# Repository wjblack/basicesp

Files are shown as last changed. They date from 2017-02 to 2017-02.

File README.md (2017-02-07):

BasicESP Hardware
=================

Introduction
------------

This repository houses the PCB design for the BasicESP project.  The
[ESP8266](https://en.wikipedia.org/wiki/ESP8266) is a super-cheap chip that
has:

   * 802.11n WiFi
   * An 80 MHz Tensilica Xtensa microcontroller
   * 64+96k of I+D RAM
   * An SDIO interface
   * And a bunch of GPIO, PWM, and other SoCish goodness

It can be used either as a SDIO-attached device or as a standalone
microcontroller and is available for about $2 via
[AliExpress](http://aliexpress.com) on a module such as the
[ESP-12F](http://www.esp8266.com/viewtopic.php?f=5&t=5520), which is what this
PCB design assumes.  Assuming an ESP-12, this board adds:

   * 2mm pads for the ESP wifi module (the board has overhang/clearance space
     for the module so that the antenna gets no interference from the board).
     This makes it very easy to mount the ESP to the board via 2mm header pins.
   * Built-in 5V->3.3V regulator.
   * A programming switch (to easily put the ESP into programming mode on boot).
   * A serial header (to easily attach an
     [FTDI cable](https://www.sparkfun.com/products/9718)).
   * All the various resistors needed for mode setting and whatnot.

Revisions
---------

[Revison 1](rev1/) was the first pass and was produced in a small batch at
[PCBWay](http://pcbway.com) in January 2017.  It lacked some filter capacitors
that caused issues with some sensors and had various other shortcomings (see
the docs inside for details).

[Revision 2](rev2/) is being produced now at PCBWay.  It includes filter caps
on the power regulator, mounting holes, a power cutoff jumper, and more pins
broken out.

Thanks
------

Many thanks to Niklas Wennerstrand for his excellent series of [intro videos
for kicad on Youtube](https://www.youtube.com/watch?v=uT1QnBSRLHs).  His notes
on producing the output for the manufacturer were particularly useful.

Copying
-------

(C) 2016-17 by [BJ Black](mailto:bj@wjblack.com)

This design is released under the [WTFPL](http://www.wtfpl.net/about/) license
and escapes unto an unsuspecting planet with NO WARRANTY WHATSOEVER, expressed
or implied.  Have fun, ya filthy animals ;-)

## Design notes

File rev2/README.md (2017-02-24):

BasicESP Hardware Revision 2.0
==============================

Introduction
------------

This PCB design is the second in the basicesp line.  The basicesp is designed
to use the ESP-12 module and has:

   * 2mm pads for the ESP wifi module (the board has overhang/clearance space
     for the module so that the antenna gets no interference from the board)
   * Built-in 5V->3.3V regulator
   * A programming switch
   * A serial header
   * All the various resistors needed for mode setting

A GPIO header on the left side has the following pinout (from the top):

   1. ADC
   2. GPIO5 (NodeMCU IO Index 1)
   3. GPIO4 (Index 2)
   4. GPIO16 (Index 0)
   5. GPIO14 (Index 5)
   6. GPIO12 (Index 6)
   7. GPIO13 (Index 7)
   8. +5V
   9. GND
   10. +3.3V

Notably an I2C display (like the Sainsmart LCD2004 controller) can be wired
straight to pins 3-6 without any gymnastics.  A typical PIR motion sensor
module can be wired to pins 4-6 with minimal gymnastics (swapping the OUT and
either VCC or GND connection to match ends).

Production and Files
--------------------

This board was sent to manufacture on 6 Feb 2017.

The design was done using kicad for both schematic, netlist, and PCB layout.
The kicad source files are all in [kicad/](kicad/).

When assembled, the board should look like this:

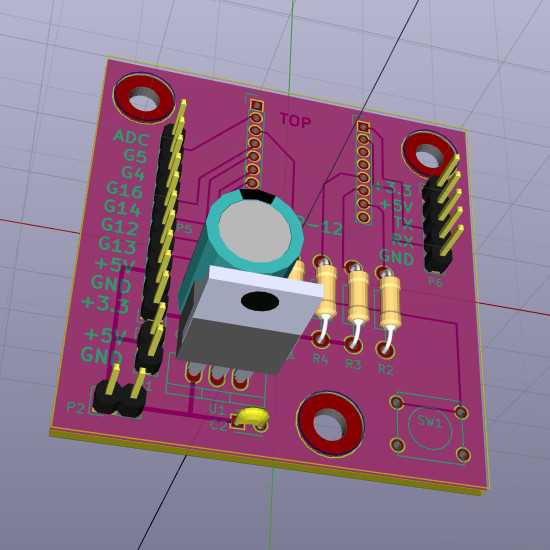
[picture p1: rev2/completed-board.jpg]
Completed board


And here is a [PDF of the schematic](schematic.pdf).

Shortcomings
------------

Revision A had two disconnected nodes (notably the +5V through the power header
and a filled region break for ground).  That's been fixed in rev 2.0b.

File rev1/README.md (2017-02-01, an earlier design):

BasicESP Hardware Revision 1.0
==============================

Introduction
------------

This PCB design was the first manufactured in the basicesp line.  The basicesp
is designed to use the ESP-12 module and has:

   * 2mm pads for the ESP wifi module (the board has overhang/clearance space
     for the module so that the antenna gets no interference from the board)
   * Built-in 5V->3.3V regulator
   * A programming switch
   * A serial header
   * All the various resistors needed for mode setting

A GPIO header on the left side has the following pinout (from the top):

   1. GPIO16 (NodeMCU IO Index 0)
   2. GPIO14 (Index 5)
   3. GPIO12 (Index 6)
   4. GPIO13 (Index 7)
   5. +5V
   6. GND
   7. +3.3V

Notably an I2C display (like the Sainsmart LCD2004 controller) can be wired
straight to pins 3-6 without any gymnastics.  A typical PIR motion sensor
module can be wired to pins 4-6 with minimal gymnastics (swapping the OUT and
either VCC or GND connection to match ends).

Production and Files
--------------------

This board was produced in a 10-unit proto batch at pcbway in Jan, 2017.  The
file bundle I sent to them is in basicesp.wjblack.com.rev.1.0b.zip.

The design was done using kicad for both schematic, netlist, and PCB layout.
The kicad source files are all in [kicad/](kicad/).

When assembled, the board looks like this:

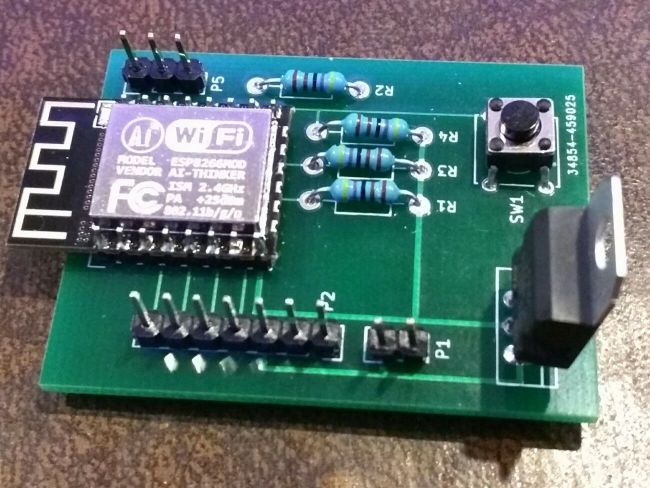
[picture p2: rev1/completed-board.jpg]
Completed board


And here is a [PDF of the schematic](schematic.pdf).

Ease of Use
-----------

Developing with this board isn't too bad (indeed, it's much easier to solder up than the 16 individual wires I had to wire for other projects involving the
PIA 2mm pitch).

The parts are surprisingly not too heat-sensitive--I was able to get away with
a fine tip soldering iron and light solder direct on all joints (there are a
lot of plain header connects, which are just straightforward through-hole
soldering).

Shortcomings
------------

The biggest problem with this design is that it does not include the
manufacturer-recommended capacitors for the 3.3V regulator.  The ESP module
doesn't seem to care too much, but variations in power wreak havoc with the PIR
module I tried (soldering the caps directly to the regulator pins afterward
worked well to mitigate those problems).  This will be fixed in Rev 2.

Mounting holes will be added in Rev 2.

It would have been nice to put a +5V rail by the serial so it could be powered
(albeit temporarily) by a FTDI cable all on one side (the evils of attempting
this are debatable--you can *kinda* get away with it if the ESP isn't drawing
too much current.  Real EEs' heads will be exploding right about now, though).
A power and/or reset switch would be a nice-to-have, as would breaking out the
two GPIO pins I left NC.

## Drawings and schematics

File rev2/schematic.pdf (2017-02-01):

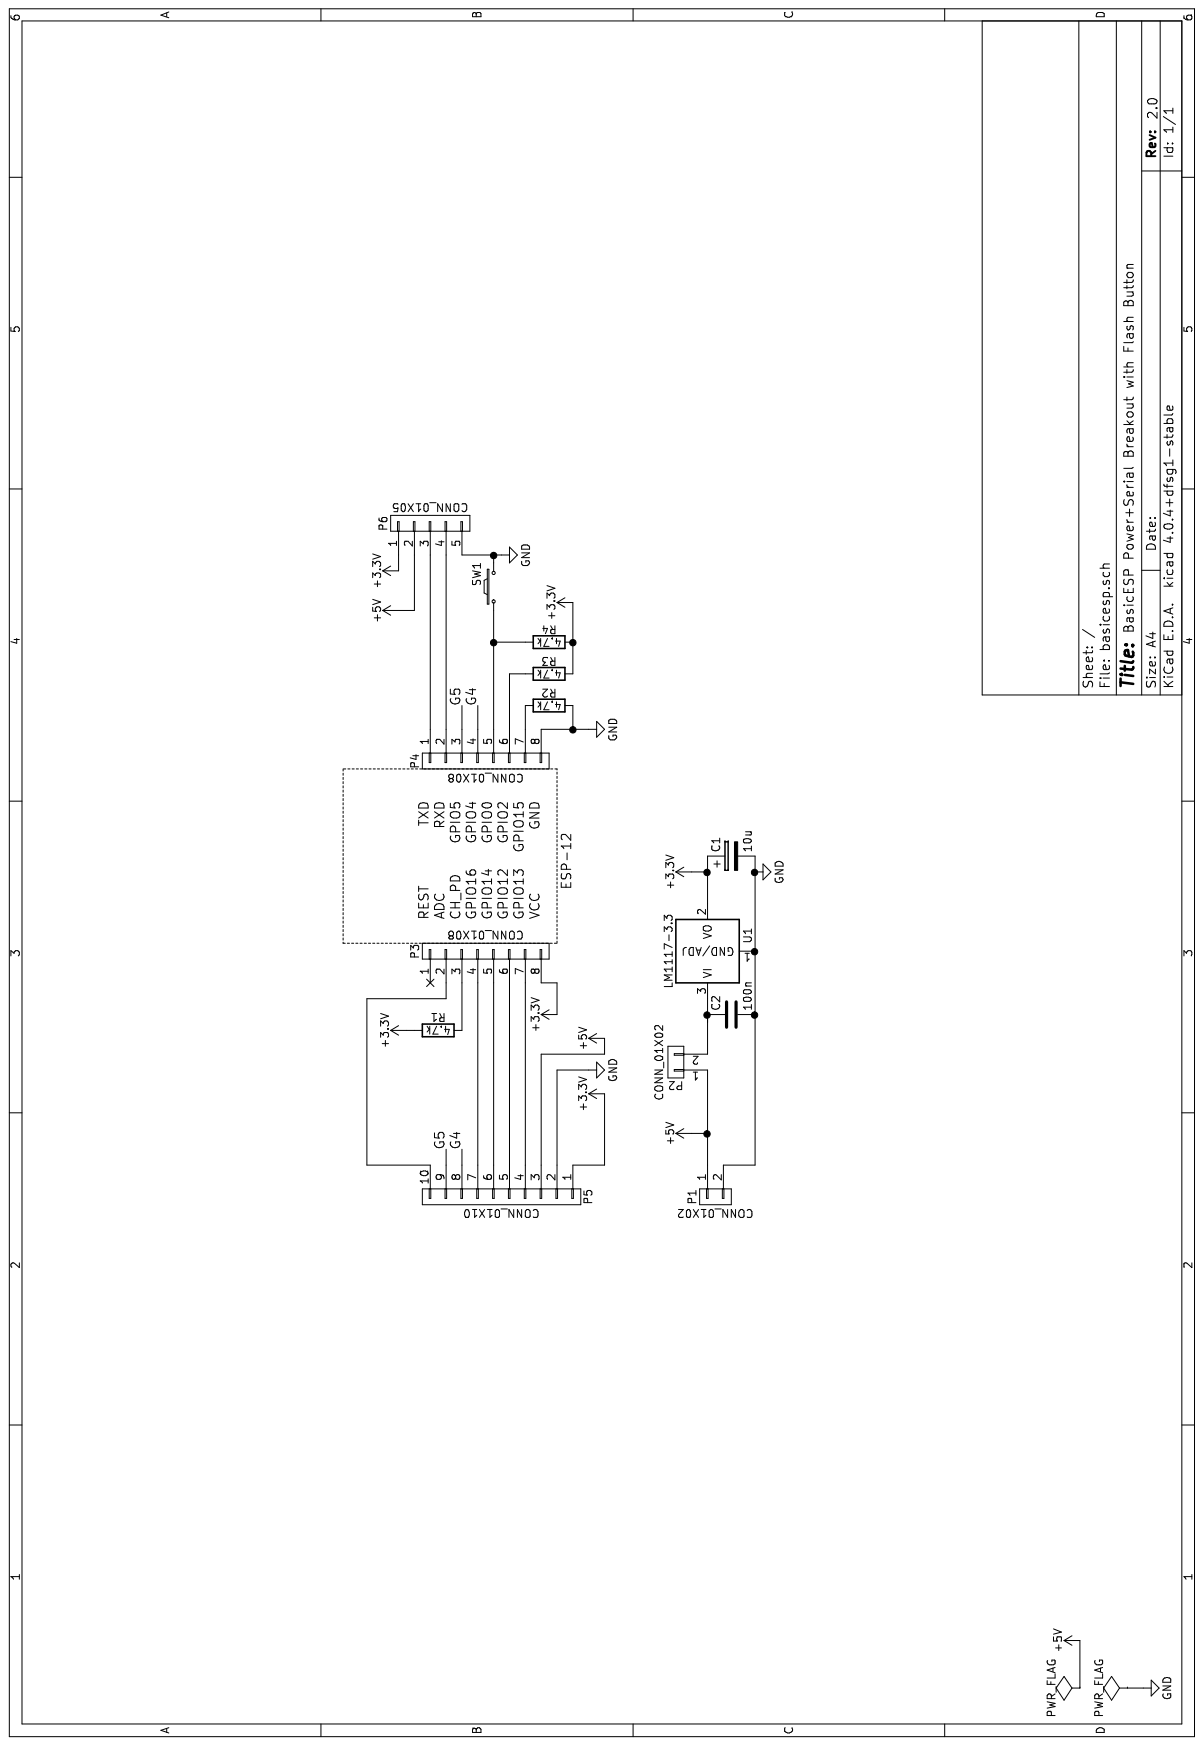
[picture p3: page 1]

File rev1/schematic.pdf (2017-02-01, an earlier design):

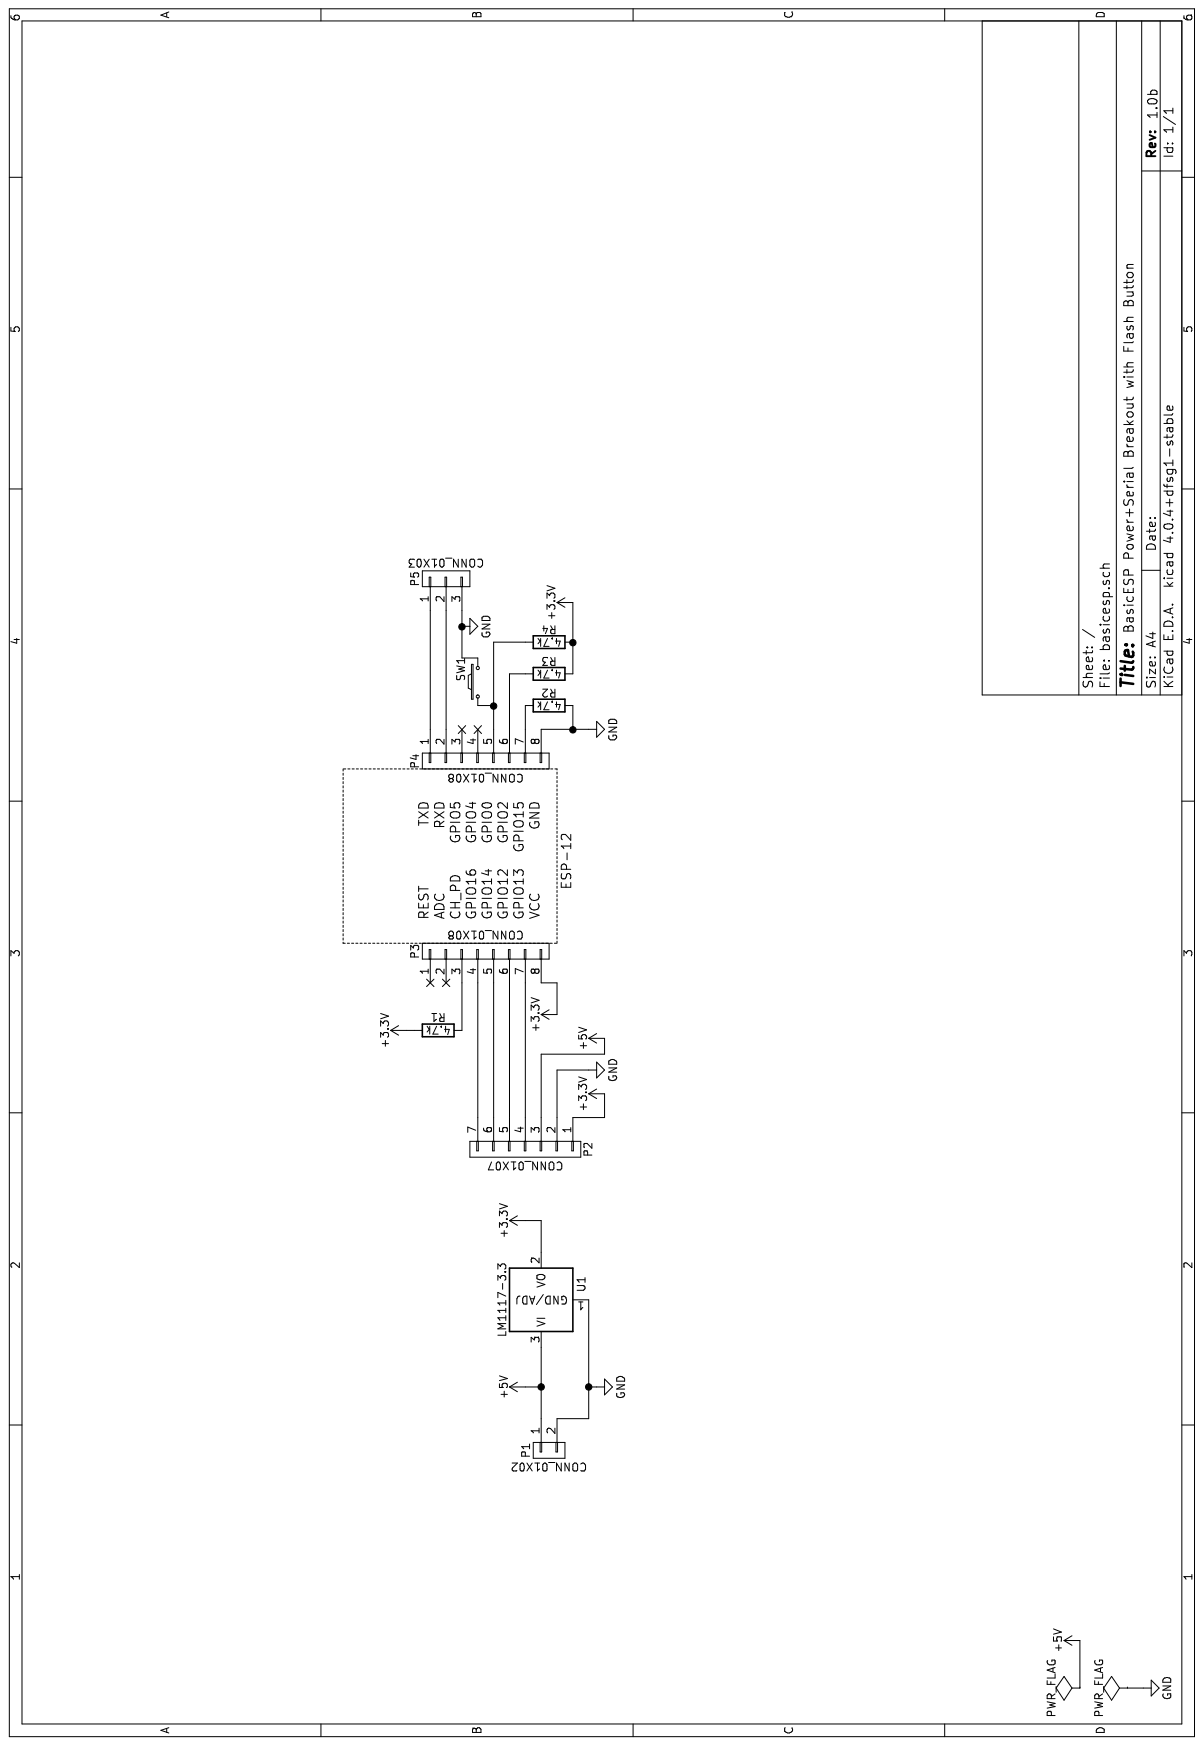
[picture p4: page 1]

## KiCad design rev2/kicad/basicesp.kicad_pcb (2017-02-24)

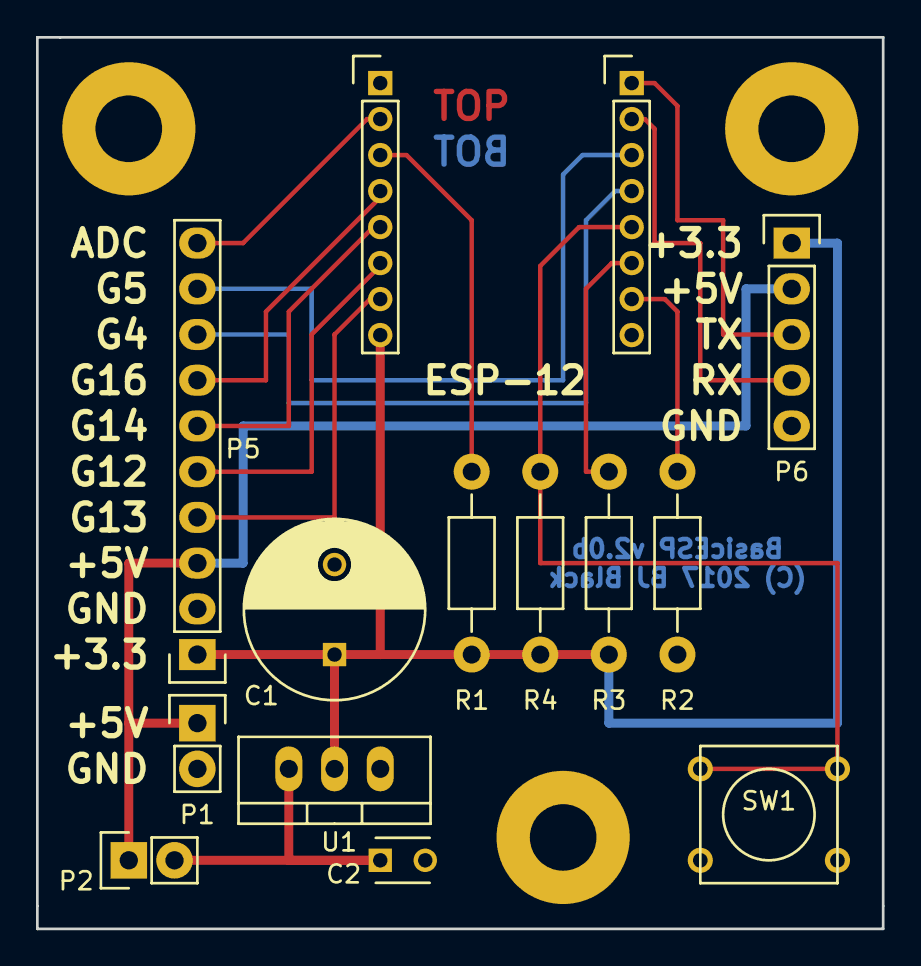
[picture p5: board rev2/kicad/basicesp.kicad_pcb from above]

Board: 2 copper layers, 47.0 x 49.5 mm, 14 parts (0 on the bottom side), 17 nets.

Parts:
C1: 10u; C_Radial_D10_L16_P5
C2: 100n; C_Disc_D3_P2.5
P1, P2: CONN_01X02; Pin_Header_Straight_1x02
P3, P4: CONN_01X08; Pin_Header_Straight_1x08_Pitch2.00mm
P5: CONN_01X10; Pin_Header_Straight_1x10
P6: CONN_01X05; Pin_Header_Straight_1x05
R1, R2, R3, R4: 4.7k; Resistor_Horizontal_RM10mm
SW1: SW_PUSH_SMALL_H; SW_PUSH_SMALL
U1: LM1117-3.3; TO-220_Neutral123_Vertical

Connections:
+3V3: C1.1, P3.8, P5.1, P6.1, R1.1, R3.2, R4.2, U1.2
+5V: P1.1, P2.1, P5.3, P6.2
/G4: P4.4, P5.8
/G5: P4.3, P5.9
GND: C1.2, C2.2, P1.2, P4.8, P5.2, P6.5, R2.2, SW1.2, U1.1
unnamed: C2.1, P2.2, U1.3
unnamed: P3.2, P5.10
unnamed: P3.3, R1.2
unnamed: P3.4, P5.7
unnamed: P3.5, P5.6
unnamed: P3.6, P5.5
unnamed: P3.7, P5.4
unnamed: P4.1, P6.3
unnamed: P4.2, P6.4
unnamed: P4.5, R4.1, SW1.1
unnamed: P4.6, R3.1
unnamed: P4.7, R2.1

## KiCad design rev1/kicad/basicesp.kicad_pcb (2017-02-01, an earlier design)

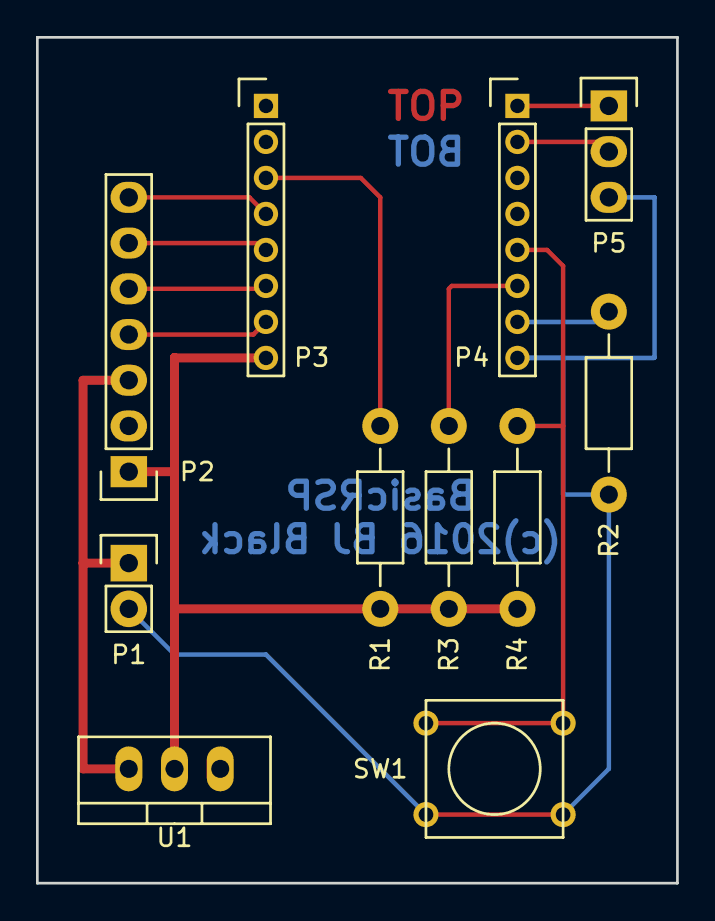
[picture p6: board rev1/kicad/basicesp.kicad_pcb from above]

Board: 2 copper layers, 35.6 x 47.0 mm, 11 parts (0 on the bottom side), 13 nets.

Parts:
P1: CONN_01X02; Pin_Header_Straight_1x02
P2: CONN_01X07; Pin_Header_Straight_1x07
P3, P4: CONN_01X08; Pin_Header_Straight_1x08_Pitch2.00mm
P5: CONN_01X03; Pin_Header_Straight_1x03
R1, R2, R3, R4: 4.7k; Resistor_Horizontal_RM10mm
SW1: SW_PUSH_SMALL_H; SW_PUSH_SMALL
U1: LM1117-3.3; TO-220_Neutral123_Vertical

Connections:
+3V3: P2.1, P3.8, R1.1, R3.2, R4.2, U1.2
+5V: P1.1, P2.3, U1.3
GND: P1.2, P2.2, P4.8, P5.3, R2.2, SW1.2, U1.1
unnamed: P2.4, P3.7
unnamed: P2.5, P3.6
unnamed: P2.6, P3.5
unnamed: P2.7, P3.4
unnamed: P3.3, R1.2
unnamed: P4.1, P5.1
unnamed: P4.2, P5.2
unnamed: P4.5, R4.1, SW1.1
unnamed: P4.6, R3.1
unnamed: P4.7, R2.1

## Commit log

2017-02-01 Initial commit.
    [basicesp.kicad_pcb, basicesp.sch]
2017-02-24 Update to revision B (fix two disconnected nodes).
    [basicesp.kicad_pcb]

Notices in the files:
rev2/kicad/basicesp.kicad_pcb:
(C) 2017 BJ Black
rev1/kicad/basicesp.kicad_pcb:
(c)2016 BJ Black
